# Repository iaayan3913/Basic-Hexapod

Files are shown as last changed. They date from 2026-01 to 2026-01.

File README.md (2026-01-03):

# 8-DOF DIY Quadruped Robot

A low-cost, 3D-printable quadruped robot powered by an **Arduino** and the **PCA9685 servo driver**.  
This project features a suite of pre-programmed animations such as waving, pushups, and bowing.

Wave animation

---

## 📋 Table of Contents
- [Features](#-features)
- [Hardware Requirements](#️-hardware-requirements)
- [Wiring Guide](#-wiring-guide)
- [Software Setup](#-software-setup)
- [Calibration](#️-calibration)

---

## 🌟 Features
- **8 Degrees of Freedom**  
  - 4 legs with **Hip** and **Knee** joints
- **Object-Oriented Control**  
  - Custom C++ classes for joint abstraction and mirroring
- **Animations**
  - 👋 **Wave** – Balances on 3 legs and waves
  - 💤 **Sleep / Wake** – Smooth transitions between poses
  - 💪 **Pushups** – Demonstrates torque coordination
  - 🙇 **Bow & Sit** – Dog-like tricks
- **Interactive Calibration**  
  - Serial-based tuning of servo limits

---

## 🛠️ Hardware Requirements
- **Microcontroller:** Arduino Uno R3 (or compatible)
- **Servo Driver:** PCA9685 16-Channel 12-bit PWM Driver (I2C)
- **Actuators:**  
  - 8× SG90 Micro Servos  
  - *(MG90S recommended for metal gears)*
- **Power Supply:**  
  - 5V **2A or higher** (USB wall adapter or power bank)

⚠️ **Important:**  
Do **NOT** power servos directly from the Arduino 5V pin.

- **Chassis:**  
  - Custom 3D-printed parts (see `/Final_Prints` folder)

---

## 🔌 Wiring Guide

This project uses the **Adafruit_PWMServoDriver** library.

### PCA9685 → Arduino
| PCA9685 | Arduino Uno |
|---|---|
| VCC | 5V |
| GND | GND |
| SDA | A4 |
| SCL | A5 |

---

### Servo Channel Mapping

| Leg | Hip Channel | Knee Channel |
|----|---|---|
| Front Left (FL) | 0 | 4 |
| Front Right (FR) | 1 | 5 |
| Back Left (BL) | 2 | 6 |
| Back Right (BR) | 3 | 7 |

---

## 💾 Software Setup
1. **Install Arduino IDE**  
   - Download from: https://www.arduino.cc/en/software

2. **Install Required Library**
   - Open Arduino IDE  
   - Go to **Tools → Manage Libraries**
   - Search for **Adafruit PWM Servo Driver**
   - Install the latest version

3. **Upload the Code**
   - Open a code from the `/Codes` folder
   - Connect Arduino via USB
   - Select the correct **Board** and **Port**
   - Click **Upload**

---
## Conclusion from this project 
This project has allowed me to experiment with many different features of a spider robot. I have experimented with inverse kinmatics as well as controlling servos from PWM signals alone. However some of the setbacks of this model were the CAD model and the servos. The model does not fully secure the hip mount to the servo and causing it to fall off in high load situations. The lack of tolerance also creates alot of friction causing the servo to struggle further under load. These are also the SG90 servos which are notoriously weak. An improvement would be to use the metal geared servos or scale this up to account for larger stronger servos.

The next stage would be to increase the degrees of freedom and make a more articulated spider robot.

---

## ⚙️ Calibration

Each servo behaves slightly differently. If the legs are not straight or symmetrical, adjust the pulse limits:

```cpp
// Located at the top of the .ino file
#define SERVOMIN  110  // Minimum pulse length (≈ 0°)

#define SERVOMAX  550  // Maximum pulse length (≈ 180°)

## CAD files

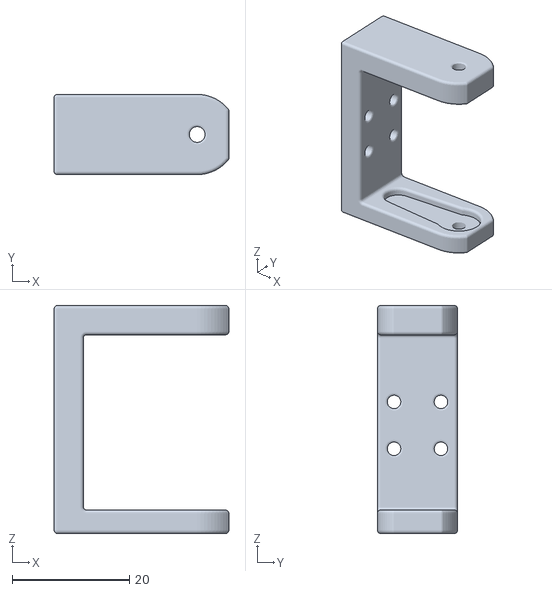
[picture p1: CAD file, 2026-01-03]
Final_Prints/LInkages.stl
29.8 x 13.7 x 38.9

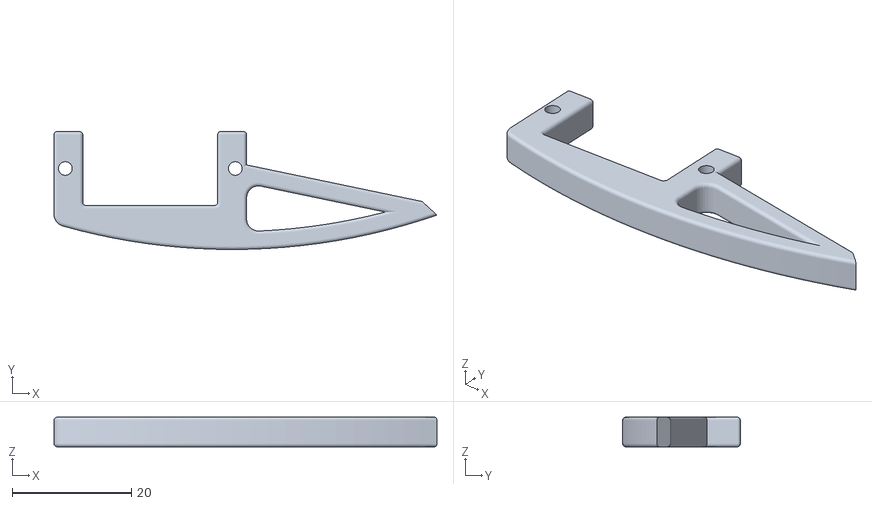
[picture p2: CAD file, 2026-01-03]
Final_Prints/Leg.stl
64.2 x 19.8 x 5.00

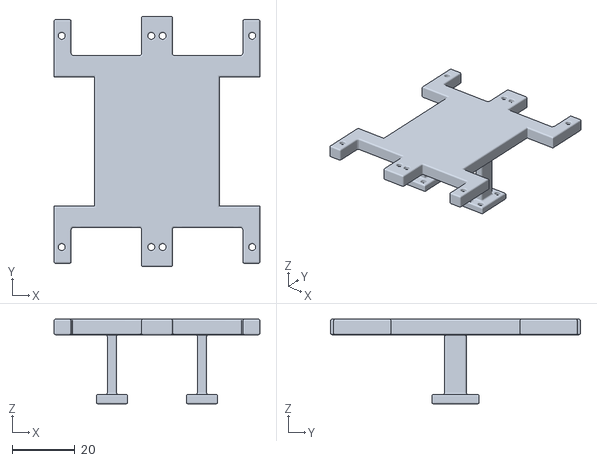
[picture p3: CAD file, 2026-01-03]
Final_Prints/ServoBase.stl
65.5 x 79.6 x 27.0

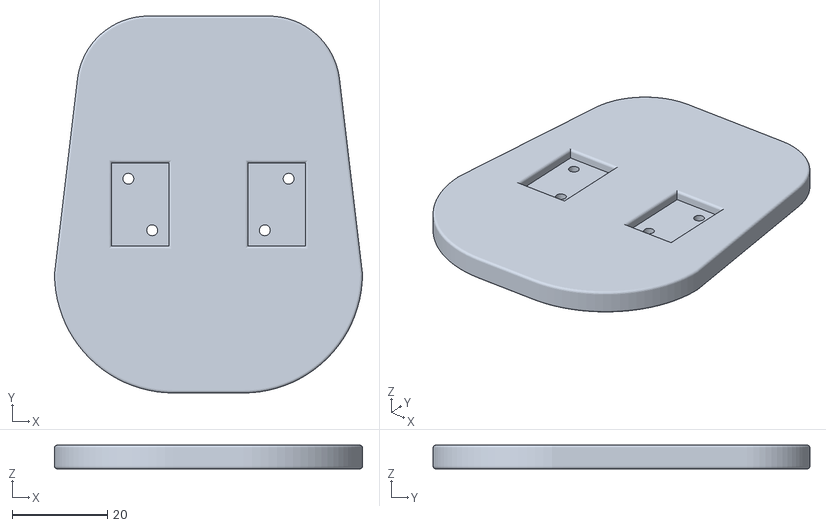
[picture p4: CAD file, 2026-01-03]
Final_Prints/UpperBase.stl
64.7 x 79.1 x 5.00

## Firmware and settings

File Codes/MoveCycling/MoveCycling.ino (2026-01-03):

#include <Wire.h>
#include <Adafruit_PWMServoDriver.h>

Adafruit_PWMServoDriver pwm = Adafruit_PWMServoDriver();

// --- Calibrated Settings ---
#define SERVOMIN  110 
#define SERVOMAX  550 

// --- Posture Settings ---
#define KNEE_STAND     25   // Standing height
#define KNEE_SLEEP     90   // Fully tucked/flat
#define KNEE_PUSHUP_DOWN 80 // Low position for pushups
#define HIP_CENTER     25   // Neutral stance

// --- Speed Settings ---
#define SLOW_SPEED     15
#define FAST_SPEED     5

// --- The Servo Joint Class ---
class ServoJoint {
  private:
    int channel;    
    bool isInverse; 
    String name;
    int currentAngle; // Robot remembers where it is

  public:
    ServoJoint(String n, int ch, bool inverse) {
      name = n;
      channel = ch;
      isInverse = inverse;
      currentAngle = 90; // Default startup assumption
    }

    void setAngle(int angle) {
      currentAngle = angle;
      int finalAngle = angle;

      // Inverse Logic
      if (isInverse) {
        finalAngle = 180 - angle;
      }
      
      finalAngle = constrain(finalAngle, 0, 180);
      uint16_t pulseLength = map(finalAngle, 0, 180, SERVOMIN, SERVOMAX);
      pwm.setPWM(channel, 0, pulseLength);
    }
    
    int getAngle() {
      return currentAngle;
    }
};

// --- Create the 8 Joints ---
// HIPS
ServoJoint FL_Hip("FL_Hip", 0, true);   
ServoJoint FR_Hip("FR_Hip", 1, false);  
ServoJoint BL_Hip("BL_Hip", 2, false);  
ServoJoint BR_Hip("BR_Hip", 3, true);   

// KNEES
ServoJoint FL_Knee("FL_Knee", 4, true); 
ServoJoint FR_Knee("FR_Knee", 5, true);  
ServoJoint BL_Knee("BL_Knee", 6, true); 
ServoJoint BR_Knee("BR_Knee", 7, true);  

// --- HELPER DECLARATIONS ---
void smoothMove(ServoJoint &joint, int targetAngle, int speedDelay);
void sleep();
void wake();
void wave();
void pushUps();
void sit();
void bow();

void setup() {
  Serial.begin(9600);
  pwm.begin();
  pwm.setPWMFreq(50);
  delay(10);

  // 1. Start in Sleep Mode (Lying down)
  Serial.println("Starting in Sleep Mode...");
  sleep();
  delay(1000);

  // 2. Wake Up
  Serial.println("Waking Up...");
  wake();
  delay(1000);

  // 3. Push Ups
  Serial.println("Push Ups...");
  pushUps();
  delay(1000);

  // 4. Sit
  Serial.println("Sitting...");
  sit();
  delay(2000);
  wake(); // Stand back up
  delay(1000);

  // 5. Bow
  Serial.println("Bowing...");
  bow();
  delay(2000);
  wake(); // Stand back up
  delay(1000);

  // 6. Wave Hello (Your Modified Version)
  Serial.println("Waving...");
  wave();
  delay(1000);
  
  // 7. Go back to sleep
  Serial.println("Going to sleep...");
  sleep();
  delay(1000);

  Serial.println("Going back to initial position...");
  Initial();
}

void loop() {
  // Main loop is empty because we ran the demo in setup()
}

// --- HELPER: Smooth Move ---
// Moves from the CURRENT angle to the TARGET angle
void smoothMove(ServoJoint &joint, int targetAngle, int speedDelay) {
  int startAngle = joint.getAngle();
  
  if (startAngle < targetAngle) {
    for (int i = startAngle; i <= targetAngle; i++) {
      joint.setAngle(i);
      delay(speedDelay);
    }
  } else {
    for (int i = startAngle; i >= targetAngle; i--) {
      joint.setAngle(i);
      delay(speedDelay);
    }
  }
}

// --- ANIMATION: Sleep ---
// Lays flat on the floor
void sleep() {
  // 1. Move Hips to Center first
  smoothMove(FL_Hip, HIP_CENTER, SLOW_SPEED);
  smoothMove(FR_Hip, HIP_CENTER, SLOW_SPEED);
  smoothMove(BL_Hip, HIP_CENTER, SLOW_SPEED);
  smoothMove(BR_Hip, HIP_CENTER, SLOW_SPEED);
  
  // 2. Fold Knees (Tuck in to 90)
  smoothMove(FL_Knee, KNEE_SLEEP, SLOW_SPEED);
  smoothMove(FR_Knee, KNEE_SLEEP, SLOW_SPEED);
  smoothMove(BL_Knee, KNEE_SLEEP, SLOW_SPEED);
  smoothMove(BR_Knee, KNEE_SLEEP, SLOW_SPEED);
}

// --- ANIMATION: Wake ---
// Stands up tall
void wake() {
  // 1. Set Hips to Center
  FL_Hip.setAngle(HIP_CENTER);
  FR_Hip.setAngle(HIP_CENTER);
  BL_Hip.setAngle(HIP_CENTER);
  BR_Hip.setAngle(HIP_CENTER);
  
  // 2. Lift Knees to Standing Height (25)
  smoothMove(FL_Knee, KNEE_STAND, SLOW_SPEED);
  smoothMove(FR_Knee, KNEE_STAND, SLOW_SPEED);
  smoothMove(BL_Knee, KNEE_STAND, SLOW_SPEED);
  smoothMove(BR_Knee, KNEE_STAND, SLOW_SPEED);
}

// --- ANIMATION: Push Ups ---
void pushUps() {
  for(int i=0; i<3; i++) {
    // Down (knees bend to 80)
    smoothMove(FL_Knee, KNEE_PUSHUP_DOWN, FAST_SPEED);
    smoothMove(FR_Knee, KNEE_PUSHUP_DOWN, FAST_SPEED);
    smoothMove(BL_Knee, KNEE_PUSHUP_DOWN, FAST_SPEED);
    smoothMove(BR_Knee, KNEE_PUSHUP_DOWN, FAST_SPEED);
    delay(200);
    // Up (knees straighten to 25)
    smoothMove(FL_Knee, KNEE_STAND, FAST_SPEED);
    smoothMove(FR_Knee, KNEE_STAND, FAST_SPEED);
    smoothMove(BL_Knee, KNEE_STAND, FAST_SPEED);
    smoothMove(BR_Knee, KNEE_STAND, FAST_SPEED);
    delay(200);
  }
}

// --- ANIMATION: Sit ---
// Back legs down, Front legs up
void sit() {
  // Lower Back Legs
  smoothMove(BL_Knee, KNEE_SLEEP, SLOW_SPEED);
  smoothMove(BR_Knee, KNEE_SLEEP, SLOW_SPEED);
  // Ensure Front Legs are Standing (in case we weren't already)
  smoothMove(FL_Knee, KNEE_STAND, SLOW_SPEED);
  smoothMove(FR_Knee, KNEE_STAND, SLOW_SPEED);
}

// --- ANIMATION: Bow ---
// Front legs down, Back legs up
void bow() {
  // Lower Front Legs
  smoothMove(FL_Knee, KNEE_SLEEP, SLOW_SPEED);
  smoothMove(FR_Knee, KNEE_SLEEP, SLOW_SPEED);
  // Ensure Back Legs are Standing
  smoothMove(BL_Knee, KNEE_STAND, SLOW_SPEED);
  smoothMove(BR_Knee, KNEE_STAND, SLOW_SPEED);
}

// --- ANIMATION: Wave (User Modified) ---
void wave() {
  // 1. Counterbalance: Move Front Right Leg forward to stabilize
  smoothMove(FR_Hip, 60, SLOW_SPEED);
  delay(200);

  // 2. Lift FL Leg high (Knee goes to 180)
  smoothMove(FL_Knee, 180, SLOW_SPEED); 
  
  // 3. Wiggle FL Knee
  for (int i = 0; i < 3; i++) {
    smoothMove(FL_Knee, 180, FAST_SPEED); // Wave Out
    smoothMove(FL_Knee, 90, FAST_SPEED);  // Wave In
  }
  delay(500);

  // 4. Wiggle FL Hip
  FL_Knee.setAngle(170);
  for (int i = 0; i < 3; i++) {
    smoothMove(FL_Hip, 80, FAST_SPEED); // Wave Out
    smoothMove(FL_Hip, 20, FAST_SPEED); // Wave In
  }
  
  // 5. Return to Center
  smoothMove(FL_Hip, HIP_CENTER, SLOW_SPEED);
  
  // 6. Put Foot Down
  smoothMove(FL_Knee, KNEE_STAND, SLOW_SPEED);
  
  // 7. Reset Counterbalance Leg
  smoothMove(FR_Hip, HIP_CENTER, SLOW_SPEED);
}

void Initial() { 
  smoothMove(FL_Hip, 90, SLOW_SPEED);
  smoothMove(FR_Hip, 90, SLOW_SPEED);
  smoothMove(BL_Hip, 90, SLOW_SPEED);
  smoothMove(BR_Hip, 90, SLOW_SPEED);

  smoothMove(FL_Knee, 25, SLOW_SPEED);
  smoothMove(FR_Knee, 25, SLOW_SPEED);
  smoothMove(BL_Knee, 25, SLOW_SPEED);
  smoothMove(BR_Knee, 25, SLOW_SPEED);
}

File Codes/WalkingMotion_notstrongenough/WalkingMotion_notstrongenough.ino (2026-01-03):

/*
    Quadruped Walking Gait - Improved Version
    
    KEY FIXES:
    - Proper state tracking for hip positions
    - Synchronized diagonal pair stepping
    - Consistent body drag timing
    - Better movement sequencing
*/

#include <Wire.h>
#include <Adafruit_PWMServoDriver.h>

Adafruit_PWMServoDriver pwm = Adafruit_PWMServoDriver();

// --- Calibrated Settings ---
#define SERVOMIN  110 
#define SERVOMAX  550 

// --- Gait Settings ---
#define WALK_SPEED     10   // Delay between small movements
#define STEP_DELAY     100  // Pause between steps
#define DRAG_SPEED     30   // Slower drag to prevent slipping

// Angles (Degrees)
#define KNEE_STAND     55   
#define KNEE_LIFT      0   

// HIP ANGLES
#define HIP_CENTER     45
#define HIP_FORWARD    65
#define HIP_BACKWARD   25

// --- The Servo Joint Class ---
class ServoJoint {
  private:
    int channel;    
    bool isInverse; 
    String name;
    int currentAngle;
    int targetAngle;  // Where we want to be

  public:
    ServoJoint(String n, int ch, bool inverse) {
      name = n;
      channel = ch;
      isInverse = inverse;
      currentAngle = 90;
      targetAngle = 90;
    }

    void setAngle(int angle) {
      currentAngle = angle;
      targetAngle = angle;
      int finalAngle = angle;

      if (isInverse) {
        finalAngle = 180 - angle;
      }
      
      finalAngle = constrain(finalAngle, 0, 180);
      uint16_t pulseLength = map(finalAngle, 0, 180, SERVOMIN, SERVOMAX);
      pwm.setPWM(channel, 0, pulseLength);
    }
    
    int getAngle() {
      return currentAngle;
    }
    
    void setTarget(int angle) {
      targetAngle = angle;
    }
    
    int getTarget() {
      return targetAngle;
    }
};

// --- Create the 8 Joints ---
ServoJoint FL_Hip("FL_Hip", 0, true);   
ServoJoint FR_Hip("FR_Hip", 1, false);  
ServoJoint BL_Hip("BL_Hip", 2, false);  
ServoJoint BR_Hip("BR_Hip", 3, true);   

ServoJoint FL_Knee("FL_Knee", 4, true); 
ServoJoint FR_Knee("FR_Knee", 5, true);  
ServoJoint BL_Knee("BL_Knee", 6, true); 
ServoJoint BR_Knee("BR_Knee", 7, true);  

void setup() {
  Serial.begin(9600);
  Serial.println("Initializing Walking Gait...");

  pwm.begin();
  pwm.setPWMFreq(50); 
  delay(10);
  
  // Initial Stand Position
  Serial.println("Standing Up...");
  FL_Hip.setAngle(HIP_CENTER); FR_Hip.setAngle(HIP_CENTER); 
  BL_Hip.setAngle(HIP_CENTER); BR_Hip.setAngle(HIP_CENTER);
  
  FL_Knee.setAngle(KNEE_STAND); FR_Knee.setAngle(KNEE_STAND); 
  BL_Knee.setAngle(KNEE_STAND); BR_Knee.setAngle(KNEE_STAND);
  
  delay(2000);
  Serial.println("Starting walk cycle...");
}

void loop() {
  // IMPROVED GAIT: Diagonal pairs move together
  // This creates a stable "trot" pattern
  
  // Phase 1: Step diagonal pair FL + BR
  stepDiagonalPair(FL_Hip, FL_Knee, BR_Hip, BR_Knee);
  
  // Phase 2: Drag body forward with planted legs (FR + BL)
  dragBodyForward();
  
  // Phase 3: Step diagonal pair FR + BL
  stepDiagonalPair(FR_Hip, FR_Knee, BL_Hip, BL_Knee);
  
  // Phase 4: Drag body forward with planted legs (FL + BR)
  dragBodyForward();
}

// --- Step two legs simultaneously (diagonal pair) ---
void stepDiagonalPair(ServoJoint &hip1, ServoJoint &knee1, 
                      ServoJoint &hip2, ServoJoint &knee2) {
  
  // 1. Lift both knees
  smoothMoveParallel(knee1, knee1.getAngle(), KNEE_LIFT,
                     knee2, knee2.getAngle(), KNEE_LIFT);
  
  // 2. Swing both hips forward
  smoothMoveParallel(hip1, hip1.getAngle(), HIP_FORWARD,
                     hip2, hip2.getAngle(), HIP_FORWARD);
  
  // 3. Drop both knees (plant feet)
  smoothMoveParallel(knee1, KNEE_LIFT, KNEE_STAND,
                     knee2, KNEE_LIFT, KNEE_STAND);
  
  delay(STEP_DELAY);
}

// --- Drag body forward with planted legs ---
void dragBodyForward() {
  // Calculate how much to drag based on current positions
  int dragAmount = (HIP_FORWARD - HIP_BACKWARD) / 2;
  
  // Get current positions
  int fl_start = FL_Hip.getAngle();
  int fr_start = FR_Hip.getAngle();
  int bl_start = BL_Hip.getAngle();
  int br_start = BR_Hip.getAngle();
  
  // Drag all hips backward together
  for (int i = 0; i < dragAmount; i++) {
    FL_Hip.setAngle(fl_start - i);
    FR_Hip.setAngle(fr_start - i);
    BL_Hip.setAngle(bl_start - i);
    BR_Hip.setAngle(br_start - i);
    
    delay(DRAG_SPEED);
  }
  
  delay(STEP_DELAY / 2);
}

// --- Move two servos in parallel smoothly ---
void smoothMoveParallel(ServoJoint &servo1, int start1, int end1,
                        ServoJoint &servo2, int start2, int end2) {
  
  int steps = max(abs(end1 - start1), abs(end2 - start2));
  
  for (int i = 0; i <= steps; i++) {
    // Calculate intermediate positions
    int pos1 = map(i, 0, steps, start1, end1);
    int pos2 = map(i, 0, steps, start2, end2);
    
    servo1.setAngle(pos1);
    servo2.setAngle(pos2);
    
    delay(WALK_SPEED);
  }
}

// --- Move single servo smoothly ---
void smoothMove(ServoJoint &servo, int startAngle, int endAngle) {
  if (startAngle < endAngle) {
    for (int pos = startAngle; pos <= endAngle; pos++) {
      servo.setAngle(pos);
      delay(WALK_SPEED);
    }
  } else {
    for (int pos = startAngle; pos >= endAngle; pos--) {
      servo.setAngle(pos);
      delay(WALK_SPEED);
    }
  }
}
